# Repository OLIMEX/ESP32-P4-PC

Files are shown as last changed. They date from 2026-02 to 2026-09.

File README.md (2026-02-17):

# ESP32-P4-PC
ESP32-P4 all in one computer with x4 USB hosts Audio, HDMI, MIPI CSI, MIPI DSI, LiPo battery operation, Ethernet with POE

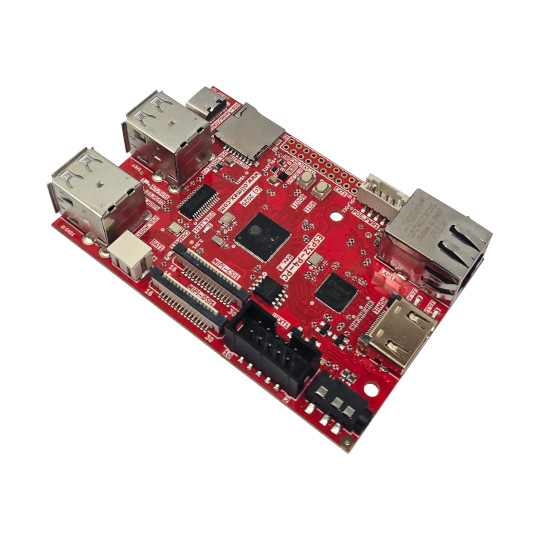
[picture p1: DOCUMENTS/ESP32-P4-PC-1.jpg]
ESP32-P4-PC-1


https://www.olimex.com/Products/IoT/ESP32-P4/ESP32-P4-PC/open-source-hardware

## Licensee
* Hardware is released under CERN Open Hardware Licence Version 2 - Strongly Reciprocal
* Software is released under MIT Licensee
* Documentation is released under CC BY-SA 4.0

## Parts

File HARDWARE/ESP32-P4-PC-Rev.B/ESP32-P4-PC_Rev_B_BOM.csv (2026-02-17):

Id | Designator | Footprint | Quantity | Designation | Supplier and ref
1 | C73,C72 | C_0402_5MIL_DWS | 2 | NA(27pF/50V/5%/C0G/C0402)
2 | FET7,FET8,FET4,FET3,FET6,FET5 | SOT23 | 6 | BSS138(SOT-23)
3 | +5V1,DC_VIN1,GND1,+5V_POE1,VBAT1,+5V_EXT1,+5V_USB1,3.3V1,VO4,GND2,CORE1,VO2,VO3,VO1 | TESTPAD_40-ROUND | 14 | TESTPAD
4 | R86,R64,R85,R48,R83,R70,R42,R43,R67,R27,R55,R66,R102,R68,R54,R41,R3 | R_0402_5MIL_DWS | 17 | 10k/R0402
5 | USB-Serial/JTAG1 | USB2.0_TYPE-C(A40-00119-A52-12)_Paste | 1 | USB-C-16P-F(A40-00119-A52-12)
6 | MIPI-CSI1,MIPI-DSI1 | TE_1-1734248-5 | 2 | FPA-VZA2-15-LF
7 | HDMI1 | HDMI-SWM-19_Paste | 1 | HDMI-SWM-19
8 | USER_LED1,LED_LINK1,LED_HOST3,LED_HOST4,LED_HOST2,LED_HOST1 | LED_0603_KA | 6 | LED/GREEN/0603
9 | C28,C27 | C_0402_5MIL_DWS | 2 | 150pF/50V/2%/NP0/C0402
10 | C38,C107,C106,C105,C95,C30,C21,C19,C7,C52,C91,C109,C112,C108,C111,C69,C4,C121,C96,C40,C53,C87,C51,C85,C46,C5,C23,C119,C42,C131,C57,C11,C49,C43,C12,C47,C32,C9,C101,C128,C94,C115,C120,C54,C31,C71 | C_0402_5MIL_DWS | 46 | 100nF/10V/20%/X5R/C0402
11 | C114,C113,C25,C80,C81,C79,C24 | C_0402_5MIL_DWS | 7 | 27pF/50V/5%/C0G/C0402
12 | BOOT1,RST1 | YTS-A016-X | 2 | YTS-A016-X
13 | R21,R12,R69,R11,R7,R10,R33,R49,R22,R37 | R_0402_5MIL_DWS | 10 | 4.7k/R0402
14 | R74,R84,R73,R88,R8,R72,R9,R91,R4,R39,R61,R82,R93,R92,R62,R56,R57,R80 | R_0402_5MIL_DWS | 18 | 2.2k/R0402
15 | R94,R90,R96 | R_0402_5MIL_DWS | 3 | 470k/R0402
16 | R26,R15,R16,R14,R25,R38 | R_0402_5MIL_DWS | 6 | 22R/R0402
17 | L4,L3 | L_2016_MM | 2 | 1.0uH/4.2A/DCR=35mR/20%/2.00x1.60x1.00mm/L2016(PIM201610-1R0MTS00)
18 | C14,C65,C74,C129,C133,C134,C136,C118,C132,C93,C130,C92 | C_0805_5MIL_DWS | 12 | 47uF/6.3V/20%/X5R/C0805
19 | C35,C102,C103,C123,C63,C75,C37,C124,C66 | C_0603_5MIL_DWS | 9 | 22uF/6.3V/20%/X5R/C0603
20 | Q6,Q2 | TSX-3.2x2.5mm_GND(3) | 2 | Q25MHz/18pF/30ppm/4P/3.2x2.5mm(ABM8-25.000MHZ-D2Y-T)
21 | Q3 | TSX-3.2x2.5mm_GND(3) | 1 | Q40.000MHz/12pF/10ppm/4P/3.2x2.5x0.70mm(Harmony_Electronics_CORP./HSX321S)
22 | R87 | R_0402_5MIL_DWS | 1 | 1M/R0402
23 | C1,C45,C2,C44 | C_0402_5MIL_DWS | 4 | 22pF/50V/5%/C0G/C0402
24 | LED_ACT1,CHARGE1 | LED_0603_KA | 2 | LED/Yellow/0603
25 | UEXT1 | GBH-254-SMT-10 | 1 | P-B-V-10-LF
26 | Q1 | CM7V-T1A(Crystal_Package-1206_3.20x1.50x0.65mm) | 1 | Q32.768kHz/12.5pF/2P/SMD1206
27 | U1 | QFN104_10mm×10mm_Pitch_0.35mm | 1 | ESP32-P4NRWxx(QFN104)
28 | R46,R47 | R_0402_5MIL_DWS | 2 | 10.5k/1%/R0402
29 | U9,U10,U11 | SLP2510P8_TEST | 3 | NA(RCLAMP0524P(SLP2510P8))
30 | C29,C6,C18,C67,C82,C99,C3,C56,C22,C68,C20,C50,C70,C76,C41 | C_0402_5MIL_DWS | 15 | 10uF/6.3V/20%/X5R/C0402
31 | C16,C15 | C_0603_5MIL_DWS | 2 | 100nF/50V/20%/Y5V/C0603
32 | U7 | SSOP28_10x4mm_Pitch_0.64mm | 1 | FE1.1s(SSOP-28)
33 | R63,R32,R19,R81 | R_0402_5MIL_DWS | 4 | NA/R0402
34 | USB_HOST3-4,USB_HOST1-2 | USB_TWO_LEVEL | 2 | USBB1-FRWH-4A(USB-Ax2)
35 | BAT1 | PH2.0-2AT(BAT) | 1 | PH2.0-2AT
36 | R76 | R_0402_5MIL_DWS | 1 | 6.04k/1%/R0402
37 | FID2,FID4,FID6,FID8 | Fiducial1x3_Paste | 4 | Fiducial
38 | U3 | SO-8_208mil | 1 | W25Q128JVSIQ(16MB)
39 | PWR1,ACT/SUS1 | LED_0603_KA | 2 | LED/RED/0603
40 | U5,U4 | SOT-563-6 | 2 | TPS62A02ADRLR(SOT-563-6)
41 | U12 | QFN64_7.5x7.5mm_Pitch_0.4mm | 1 | LT8912B(QFN64)
42 | R36 | R_0402_5MIL_DWS | 1 | 220k/R0402
43 | LAN1 | RJP-003TC1(LPJ4112CNL) | 1 | RJP-003TC1(LPJ4112CNL)
44 | R65,R75,R71 | R_0402_5MIL_DWS | 3 | 100k/R0402
45 | Q4 | TSX-3.2x2.5mm_GND(3) | 1 | Q12MHz/18pF/30ppm/4P/3.2x2.5mm(ABM8-12.000MHZ-D2Y-T)
46 | MICRO_SD1 | TFC-WPAPR-08 | 1 | TFC-WPAPR-08-LF
47 | L1,L7,L8,L2,L5,L6 | L_0805_5MIL_DWS | 6 | 600OHM/2A/UPZ2012E-601-2R0TF/0805
48 | HEADSETS1 | PJ-320D | 1 | PJ-320D
49 | C117 | CPOL-RM3.5mm_8.0x11.5mm_PTH | 1 | 1000uF/10V/20%
50 | POE_PWR1 | PH2.0-4PLB | 1 | PH2.0-4AT
51 | C62,C59 | C_0402_5MIL_DWS | 2 | NA(120pF/50V/5%/C0G/C0402)
52 | EXT1 | HN2x10 | 1 | NA(HN2x10)
53 | C60,C33 | C_0402_5MIL_DWS | 2 | NA(100nF/10V/20%/X5R/C0402)
54 | MH1,MH2,MH3 | Mounting_Hole_Drill-3.3mm_Clerance-7mm | 3 | Mounting_Hole_NPTH
55 | FID3,FID1,FID7,FID5 | Fiducial1x3 | 4 | Fiducial
56 | R13 | R_0402_5MIL_DWS | 1 | 10M/R0402
57 | DCDC_Vin1 | SJ_2_SMALL_12_TIED | 1 | Closed(1-2)
58 | C110 | C_0402_5MIL_DWS | 1 | 2.2nF/50V/10%/X7R/C0402
59 | PWR_SENS_E1,BAT_SENS_E1,BAT_SENS_E2 | SJ_1_SMALLER | 3 | Opened
60 | C61,C36,C88,C48,C97,C84,C55,C58,C98,C39,C86,C100,C10,C126,C104,C8 | C_0402_5MIL_DWS | 16 | 1uF/6.3V/10%/X5R/C0402
61 | R5,R6 | R_0402_5MIL_DWS | 2 | 5.1k/1%/R0402
62 | R103,R89 | R_0402_5MIL_DWS | 2 | 6.81k/1%/R0402
63 | C125,C135,C90,C89,C127,C116 | C_0805_5MIL_DWS | 6 | NA(47uF/6.3V/20%/X5R/C0805)
64 | R2,R1 | R_0402_5MIL_DWS | 2 | 4.02k/1%/R0402
65 | U15 | SOT-23-5 | 1 | TP4054-42-SOT25-R(SOT23-5)
66 | C122,C34,C64 | C_0603_5MIL_DWS | 3 | NA(22uF/6.3V/20%/X5R/C0603)
67 | R50 | R_0402_5MIL_DWS | 1 | 110R/1%/R0402
68 | R35,R34 | R_0402_5MIL_DWS | 2 | 1.5k/R0402
69 | R78 | R_0402_5MIL_DWS | 1 | NA(200R/R0402)
70 | L9 | L_0805_5MIL_DWS | 1 | NA(600OHM/2A/UPZ2012E-601-2R0TF/0805)
71 | R29,R30 | R_0402_5MIL_DWS | 2 | NA(2.2k/R0402)
72 | L11 | CD42(43) | 1 | 4.7uH/2.33A/DCR=70mR/20%/CD43(NRS4018T4R7MDGJ)
73 | D4 | SMA-KA | 1 | 1N5822/SS34/SMA
74 | R17 | R_0402_5MIL_DWS | 1 | 6.19k/1%/R0402
75 | R77 | R_0402_5MIL_DWS | 1 | 10R/R0402
76 | R52 | R_0402_5MIL_DWS | 1 | 240R/1%/R0402
77 | R53 | R_0402_5MIL_DWS | 1 | 2.7k/1%/R0402
78 | C26,C83 | C_0402_5MIL_DWS | 2 | NA(10uF/6.3V/20%/X5R/C0402)
79 | D2,D3 | SOD-123_1C-2A_KA | 2 | 1N5819S4(SOD123)
80 | Q5 | SOT23 | 1 | BC817-40
81 | VR2 | SOT-23-5 | 1 | AP1231-3.3V(SOT23-5)
82 | R24,R105 | R_0402_5MIL_DWS | 2 | 24.9k/1%/R0402
83 | R28,R18 | R_0402_5MIL_DWS | 2 | NA(10k/R0402)
84 | R95 | R_0402_5MIL_DWS | 1 | 8.25k/1%/R0402
85 | VR1 | SOT223 | 1 | LD1117AG-AD-AA3-A-R
86 | C77,C78 | C_0402_5MIL_DWS | 2 | 20pF/50V/5%/NP0/C0402
87 | R45 | R_0402_5MIL_DWS | 1 | 6.49k/1%/R0402
88 | R51 | R_0402_5MIL_DWS | 1 | 49.9k/1%/R0402
89 | R59,R58,R60 | R_0402_5MIL_DWS | 3 | 33R/R0402
90 | U6 | SOT23-6 | 1 | CH217K(SOT23-6L)
91 | U14 | SOT23-6 | 1 | MT3608(SOT23-6)
92 | R23 | R_0402_5MIL_DWS | 1 | NA(4.7k/R0402)
93 | R31 | R_0603_5MIL_DWS | 1 | 0R/R0603
94 | U2 | QFN32_EP(33)_4.00x4.00x0.80mm_Pitch_0.40mm | 1 | IP101GRR(32-PIN_QFN)
95 | C17 | C_1206_5MIL_DWS_ISO | 1 | 1nF/2000V/10%/X7R/C1206
96 | R98 | R_0402_5MIL_DWS | 1 | 1.05k/1%/R0402
97 | R40 | R_0402_5MIL_DWS | 1 | NA(0R/R0402)
98 | R79 | R_0402_5MIL_DWS | 1 | 200R/R0402
99 | U16,U13 | SOT-5X3 | 2 | TPS2116
100 | RM2 | RA0805_(4X0402)_xx_BIGGEROUTPADS | 1 | RA0805_(4X0402)_33R
101 | U8 | QFN-20_EP(21)_3x3x0.6mm_Pitch_0.4mm | 1 | ES8311(QFN-20)
102 | RM1 | RA0805_(4X0402)_xx_BIGGEROUTPADS | 1 | RMAT_(4x0402)_4.7k
103 | TVS1 | SOT-23-5 | 1 | ESDS314DBVR(SOT-23-5)
104 | C13 | C_0402_5MIL_DWS | 1 | 4.7uF/X5R/20%/10V/C0402
105 | FET1 | SOT23 | 1 | IRLML6402(SOT-23)
106 | R44 | R_0402_5MIL_DWS | 1 | 30.1k/1%/R0402
107 | R20 | R_0402_5MIL_DWS | 1 | NA(10M/R0402)

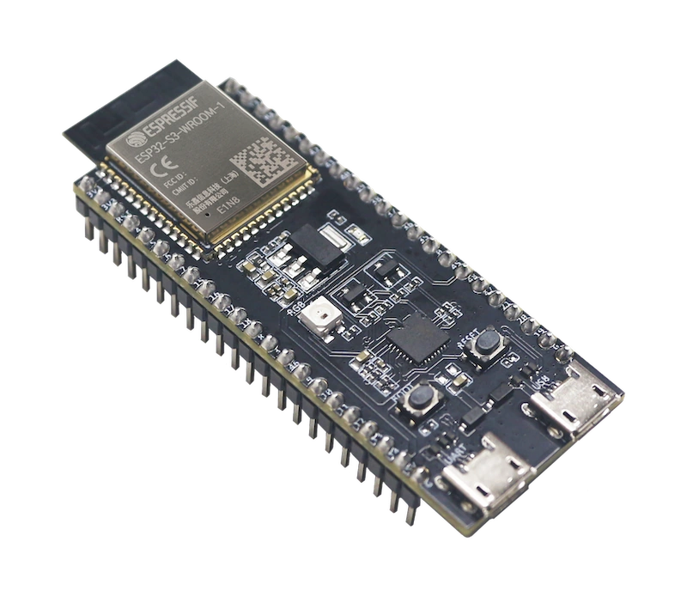
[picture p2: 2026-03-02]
SOFTWARE/ESP-IDF/p4_production_test/components/esp-bsp/bsp/esp_bsp_devkit/doc/esp_bsp_devkit.webp

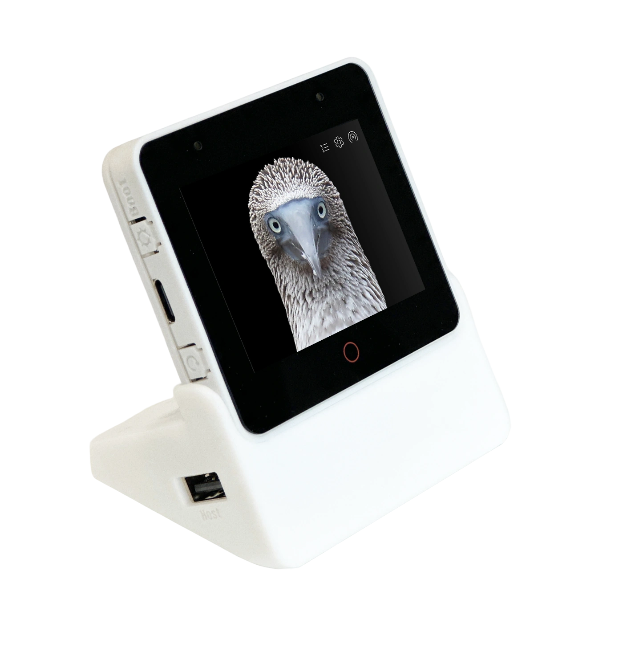
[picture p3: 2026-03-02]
SOFTWARE/ESP-IDF/p4_production_test/components/esp-bsp/bsp/esp-box-3/doc/esp-box-3.webp

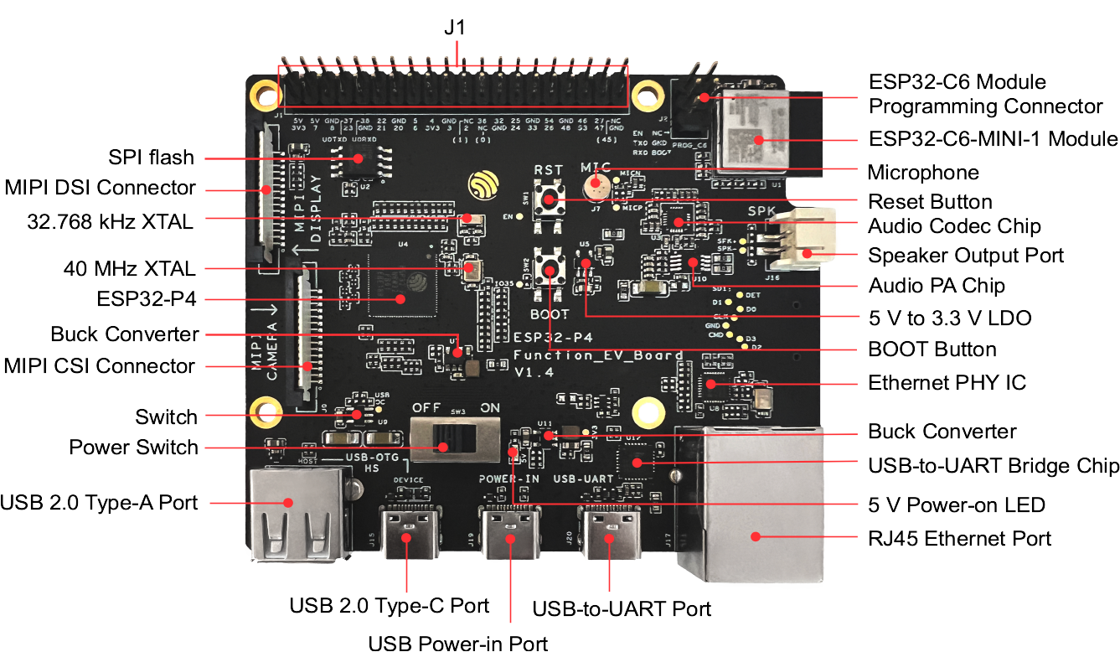
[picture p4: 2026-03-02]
SOFTWARE/ESP-IDF/p4_production_test/components/esp-bsp/bsp/esp32_p4_function_ev_board/doc/esp32-p4-function-ev-board-annotated-photo-front.png

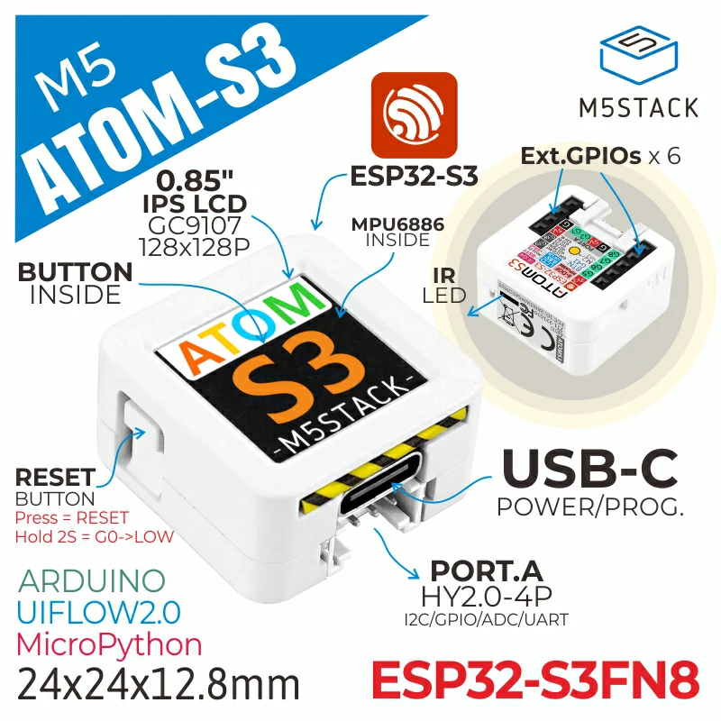
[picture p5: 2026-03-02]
SOFTWARE/ESP-IDF/p4_production_test/components/esp-bsp/bsp/m5_atom_s3/doc/pic.webp

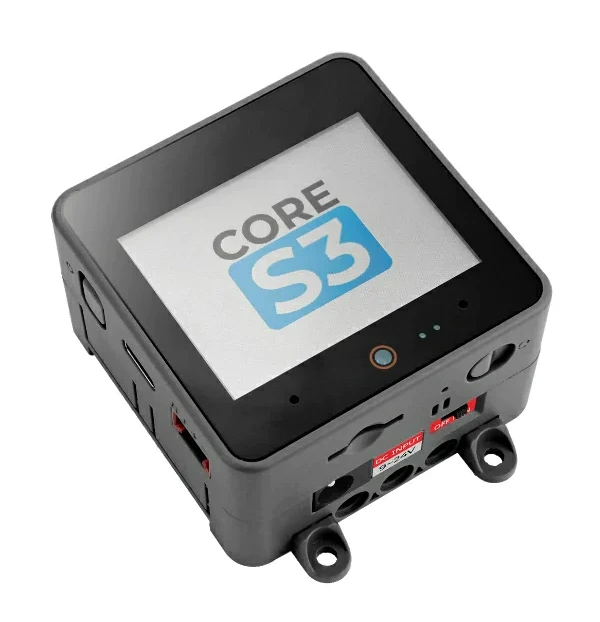
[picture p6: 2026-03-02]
SOFTWARE/ESP-IDF/p4_production_test/components/esp-bsp/bsp/m5stack_core_s3/doc/m5stack_core_s3.webp

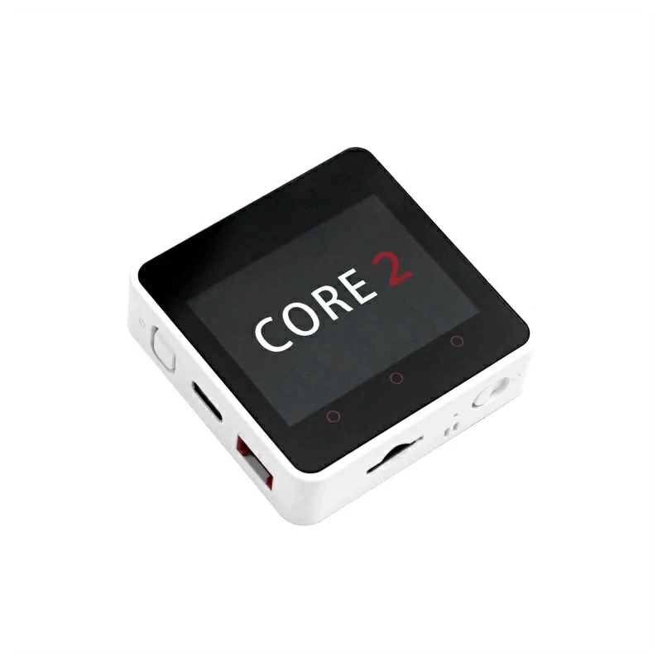
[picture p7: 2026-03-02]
SOFTWARE/ESP-IDF/p4_production_test/components/esp-bsp/bsp/m5stack_core_2/doc/m5stack_core_2.webp

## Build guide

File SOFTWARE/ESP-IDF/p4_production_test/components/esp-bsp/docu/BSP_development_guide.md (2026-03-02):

# Board Support Package development guide

This guide describes necessary steps to add a new BSP to the esp-bsp project.

### New BSP requirements
* We want the BSPs to be used by as many users and projects as possible. All BSP must support IDF from version 4.4 up to latest release. Boards that were released after IDF v5.0 do not have to be backward compatible with v4.4.
* We want the BSPs to provide a 'board abstraction layer' that allows the user to run his application on a range of different boards. Public API for each BSP must be the same. The API consistency is ensured by conventions described below.
* We want the main features to be clearly visible for new users. Each new BSP must be added to a table of supported boards in root [README.md](https://github.com/espressif/esp-bsp/blob/master/README.md) it must contain a license (Apache-2) and a README.md file. Conventions for the readme file are described below
* All BSPs are uploaded to [ESP Registry](https://components.espressif.com/). So each BSP must contain `idf_component.yml` file and must be added to [CI upload job](https://github.com/espressif/esp-bsp/blob/master/.github/workflows/upload_component.yml). The `idf_component.yml` must contain: version, description, url, target and (optional) dependencies.
* We want to provide LVGL users with easy, out-of-the-box working solution for their GUI applications. Each board that has a display must be added to LVGL's [SquareLineStudio](https://squareline.io/) pre-defined boards. For more information refer to [this readme](https://github.com/espressif/esp-bsp/blob/master/SquareLine/README.md).
    * List of currently implemented LCD drivers is maintained in a [separate table](https://github.com/espressif/esp-bsp/blob/master/docu/LCD.md)
* We have an experimental idf.py extension, [bsp_ext.py](https://github.com/espressif/esp-bsp/blob/master/examples/bsp_ext.py) that allows changing of BSP during project configuration. Please add new BSPs to the list in this file.

### API conventions

BSP is a standard IDF component. You can start development by `idf.py create-component your_bsp_name`.

The APIs that a BSP can offer depend on the boards capabilities. For example, a board that contains audio codec will expose audio API and a board with display and touch controller will expose display and touch API.

#### General
* The boards capabilities must be listed in its header file, similarly to `SOC_CAPS_*` macro used in esp-idf. For example:
``` c
/**************************************************************************************************
 *  BSP Capabilities
 **************************************************************************************************/

#define BSP_CAPS_DISPLAY        1
#define BSP_CAPS_TOUCH          1
#define BSP_CAPS_BUTTONS        1
#define BSP_CAPS_AUDIO          1
#define BSP_CAPS_AUDIO_SPEAKER  1
#define BSP_CAPS_AUDIO_MIC      1
#define BSP_CAPS_SDCARD         0
#define BSP_CAPS_IMU            1
```
* Each BSP must provide a wrapper header file that can be included by `#include "bsp/esp-bsp.h"`
* BSPs that expose display and touch APIs must provide a header file `bsp/display.h` and `bsp/touch.h` that contain functions for display/touch initialization without graphical library (LVGL)
* Complete board's pinout must be in the beginning of the BSP's header file

#### I2C
* I2C can be used by many devices on the bus. The 'init' call must support multiple invocations
* Uses Kconfig for I2C peripheral selection
* Functions, which must be defined in BSP *.c file:
``` c
esp_err_t bsp_i2c_init(void);
esp_err_t bsp_i2c_deinit(void);
```
* See any BSP

#### Display
* BSPs with display are shipped with [LVGL](https://components.espressif.com/components/lvgl/lvgl) component by default. For version without LVGL, you can use BSP version with `noglib` suffix (eg. `esp32_s3_eye_noglib`)
* Display functions are divided into two parts. The first part is HW initialization only (include/bsp/display.h), second part is initialization of the display and LVGL (bsp/esp-bsp.h)
* HW initialization functions, which must be defined in bsp/display.h file:
``` c
esp_err_t bsp_display_new(const bsp_display_config_t *config, esp_lcd_panel_handle_t *ret_panel, esp_lcd_panel_io_handle_t *ret_io);
esp_err_t bsp_display_brightness_set(int brightness_percent);
esp_err_t bsp_display_backlight_on(void);
esp_err_t bsp_display_backlight_off(void);
```
* LVGL init function, which must be defined in bsp/esp-bsp.h file:
``` c
lv_disp_t *bsp_display_start(void);
lv_disp_t *bsp_display_start_with_config(const bsp_display_cfg_t *cfg);
bool bsp_display_lock(uint32_t timeout_ms);
void bsp_display_unlock(void);
void bsp_display_rotate(lv_disp_t *disp, lv_disp_rot_t rotation);
```
* See esp_wrover_kit, esp32_s2_kaluga_kit ...

#### LCD Touch
* LCD touch drivers are build around base [esp_lcd_touch](https://components.espressif.com/components/espressif/esp_lcd_touch) component
* BSPs with touch display are shipped with [LVGL](https://components.espressif.com/components/lvgl/lvgl) component by default. For version without LVGL, you can use BSP version with `noglib` suffix (eg. `esp32_s3_eye_noglib`)
* If LVGL is used, the touch controller is initialized together with display. If LVGL is not used you can use HW initialization functions from bsp/touch.h
* HW initialization function, which must be defined in bsp/touch.h file:
``` c
esp_err_t bsp_touch_new(const bsp_touch_config_t *config, esp_lcd_touch_handle_t *ret_touch);
```
* LVGL get input device function for advanced scenarios in bsp/esp-bsp.h
``` c
lv_indev_t *bsp_display_get_input_dev(void);
```
* See esp-box, esp-box-3 ...

#### SPI Flash File System
* The SPIFFS is supported by all ESP chips internally. It allows the users to store large files (pictures, recordings...)
* Functions, which must be defined in BSP *.c file:
``` c
esp_err_t bsp_spiffs_mount(void);
esp_err_t bsp_spiffs_unmount(void);
```
* Uses Kconfig for SPIFFS settings
* See any BSP

#### SD card
* Functions, which should be defined in BSP *.c file:
``` c
esp_err_t bsp_sdcard_mount(void);
esp_err_t bsp_sdcard_unmount(void);
```
* Uses Kconfig for mountpoint and possible `format_on_fail` settings
* See esp_wrover_kit

> @todo We still use `extern sdmmc_card_t *bsp_sdcard;` which is very ugly :( Tracked in BSP-189

> @todo We could reuse code from https://github.com/espressif/esp-box/blob/master/components/bsp/src/storage/bsp_sdcard.c

#### Buttons
* We want to provide unified API for all types of buttons
* Buttons feature is covered by [button](https://components.espressif.com/components/espressif/button) component. It allows usage of GPIO, ADC, io_expander and even capacitive buttons with various events (pressed, released, double click, long press...)
* All buttons must be added to enum `bsp_button_t`
* All buttons must be initialized in the following call
``` c
esp_err_t bsp_iot_button_create(button_handle_t btn_array[], int *btn_cnt, int btn_array_size);
```
* See esp32_s2_kaluga_kit

#### LEDs
* Similarly to buttons, we want to provide unified API for all types of LEDs (classic, RGB, addressable RGB)
* LEDs feature is covered by [led_indicator](https://components.espressif.com/components/espressif/led_indicator) component. It support all aforementioned types of LEDs with various control options (brightness, color, transitions...)
* All LEDs must be initialized in the following call
``` c
esp_err_t bsp_led_indicator_create(led_indicator_handle_t led_array[], int *led_cnt, int led_array_size);
```
* See esp32_s3_korvo_1

#### Audio
* Audio feature is covered by [esp_codec_dev](https://components.espressif.com/components/espressif/esp_codec_dev) component
* BSP provides API for easy initialization:
``` c
esp_err_t bsp_audio_init(const i2s_std_config_t *i2s_config);
const audio_codec_data_if_t *bsp_audio_get_codec_itf(void);
esp_codec_dev_handle_t bsp_audio_codec_speaker_init(void);
esp_codec_dev_handle_t bsp_audio_codec_microphone_init(void);
```
* See esp32_s3_korvo_2, esp32_s2_kaluga_kit

#### Camera
* Camera feature is covered by [esp32-camera](https://components.espressif.com/components/espressif/esp32-camera) component
* There is no API needed. We only provide pinout and default camera configuration macro `BSP_CAMERA_DEFAULT_CONFIG`
* See esp32_s2_kaluga_kit, esp32_s3_eye

#### USB
* Only provide pinout for completeness
* See esp32_s3_usb_otg

### README.md conventions
> @todo tracked in BSP-362

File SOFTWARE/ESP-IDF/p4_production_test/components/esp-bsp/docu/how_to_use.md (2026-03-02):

# How to Use the ESP-BSP API

<div align="center">

| :pager: [DISPLAY & TOUCH](#pager-display--touch) | :musical_note: [AUDIO](#musical_note-audio) | :floppy_disk: [SD & SPIFFS](#floppy_disk-sd-card--spi-flash-file-storage) | :camera: [CAMERA](#camera-camera) |
| :---: | :---: | :---: | :---: |

| :radio_button: [BUTTONS](#radio_button-buttons) | :bulb: [LEDS](#bulb-leds) | :battery: [BATTERY](#battery-battery) | :electric_plug: [USB](#electric_plug-usb) | :video_game: [IMU & Sensors](#video_game-imu--sensors) |
| :---: | :---: | :---: | :---: | :---: |

</div>

## Overview

This document provides a unified overview of the ESP-BSP (Board Support Package) API. It is shared across all supported BSPs. Each BSP **may not implement all APIs listed here**, but **should provide implementations for all APIs relevant to the capabilities it supports**.

The goal of this document is to make it easier for developers to understand the available APIs and how to use them consistently across different boards.

## General

### Identification

Each BSP defines an identifier macro in the form of `BSP_BOARD_*`.

### Capabilities

Each BSP defines a set of capability macros that indicate which features are supported.
The list may look like this:

```
#define BSP_CAPS_DISPLAY        1
#define BSP_CAPS_TOUCH          1
#define BSP_CAPS_BUTTONS        1
#define BSP_CAPS_AUDIO          1
#define BSP_CAPS_AUDIO_SPEAKER  1
#define BSP_CAPS_AUDIO_MIC      1
#define BSP_CAPS_SDCARD         1
#define BSP_CAPS_IMU            0
```

You can use these macros to conditionally compile code depending on feature availability.

### Pinout

Each BSP defines a set of macros for default pin assignments used by its hardware peripherals.
These macros allow users to configure or reference standard interfaces like I2C, SPI, LCD, audio, or SD cards easily.

- I2C: `BSP_I2C_*`
- Display: `BSP_LCD_*`
- Audio I2S: `BSP_I2S_*`
- USB: `BSP_USB_*`
- SD Card (MMC): `BSP_SD_*`
- SD Card (SPI): `BSP_SD_SPI_*`

> [!NOTE]
> Not all boards support all interfaces. You should always check if the related capability macro (e.g., BSP_CAPS_SDCARD) is defined.

### I2C

Some devices included in BSPs (e.g., sensors, displays, audio codecs) communicate via the I2C interface. In many cases, I2C is initialized automatically as part of the device setup. However, you can manually initialize or deinitialize the I2C peripheral using the following API:

```
/* Initialize the default I2C bus used by the BSP */
bsp_i2c_init();

...

/* Deinitialize the I2C bus */
bsp_i2c_deinit();
```

If you need direct access to the initialized I2C bus (e.g., to communicate with an external peripheral not handled by the BSP), you can retrieve the I2C bus handle:

```
i2c_master_bus_handle_t i2c = bsp_i2c_get_handle();
```

> [!NOTE]
> The BSP ensures that I2C initialization is performed only once, even if called multiple times. This helps avoid conflicts when multiple components rely on the same I2C bus.

### ADC

Some devices included in BSPs (such as buttons, battery monitoring, etc.) use the ADC peripheral. In most cases, the ADC is automatically initialized as part of the specific device setup. However, you can manually initialize the ADC using the following API:

```
/* Initialize the ADC peripheral */
bsp_adc_initialize();
```

If you need direct access to the ADC instance (e.g., for custom measurements), you can retrieve the handle:

```
adc_oneshot_unit_handle_t adc = bsp_adc_get_handle();
```

> [!NOTE]
> The BSP ensures the ADC is initialized only once, even if `bsp_adc_initialize()` is called multiple times.

### Features

Some boards support enabling or disabling specific hardware features (such as LCD, SD card, camera, etc.) to reduce power consumption or manage shared resources. The BSP provides a unified API to control these features:

```
/* Enable the LCD feature */
bsp_feature_enable(BSP_FEATURE_LCD, true);

/* Disable the speaker to reduce power usage */
bsp_feature_enable(BSP_FEATURE_SPEAKER, false);
```

Supported feature flags (may vary depending on the board):
- `BSP_FEATURE_LCD` - Display module
- `BSP_FEATURE_TOUCH` - Touch controller
- `BSP_FEATURE_SD` - SD card interface
- `BSP_FEATURE_SPEAKER`-  Audio speaker
- `BSP_FEATURE_BATTERY` - Battery monitoring
- `BSP_FEATURE_VIBRATION` - Vibration motor

> [!NOTE]
> Not all BSPs support feature toggling, and some features may not be available or controllable via this API. Always check the BSP header or documentation for supported features.

> [!TIP]
> Disabling unused features can help reduce power consumption, especially in battery-powered applications.

## :pager: Display & Touch

### Initialization

ESP-BSP provides two ways to initialize the **display**, **touch** and **LVGL**.

Simple method:

```
/* Initialize display, touch, and LVGL */
lv_display_t display = bsp_display_start();
```

Configurable method:

```
bsp_display_cfg_t cfg = {
    .lvgl_port_cfg = ESP_LVGL_PORT_INIT_CONFIG(),   /* See LVGL Port for more info */
    .buffer_size = BSP_LCD_V_RES * BSP_LCD_H_RES,   /* Screen buffer size in pixels */
    .double_buffer = true,                          /* Allocate two buffers if true */
    .flags = {
        .buff_dma = true,                           /* Use DMA-capable LVGL buffer */
        .buff_spiram = false,                       /* Allocate buffer in PSRAM if true */
    }
};
cfg.lvgl_port_cfg.task_stack = 10000;   /* Example: change LVGL task stack size */
/* Initialize display, touch, and LVGL */
lv_display_t display = bsp_display_start_with_config(&cfg);
```

After initialization, you can use the [LVGL](https://docs.lvgl.io/master/) API or [LVGL Port](../components/esp_lvgl_port/README.md) API.

### Initialization without LVGL - NoGLIB BSP

To initialize the LCD without LVGL, use:

```
esp_lcd_panel_handle_t panel_handle;
esp_lcd_panel_io_handle_t io_handle;
const bsp_display_config_t bsp_disp_cfg = {
    .max_transfer_sz = (BSP_LCD_H_RES * 100) * sizeof(uint16_t),
};
BSP_ERROR_CHECK_RETURN_NULL(bsp_display_new(&bsp_disp_cfg, &panel_handle, &io_handle));
```

To initialize the LCD touch without LVGL, use:

```
esp_lcd_touch_handle_t tp;
bsp_touch_new(NULL, &tp);
```

After initialization, you can use the [ESP-LCD](https://docs.espressif.com/projects/esp-idf/en/latest/esp32/api-reference/peripherals/lcd/index.html) API and [ESP-LCD Touch](../components/lcd_touch/README.md) API.

### Set Brightness

```
/* Set display brightness to 100% */
bsp_display_backlight_on();

/* Set display brightness to 0% */
bsp_display_backlight_off();

/* Set display brightness to 50% */
bsp_display_brightness_set(50);
```

> [!NOTE]
> Some boards do not support changing brightness. They return an `ESP_ERR_NOT_SUPPORTED` error.

### LVGL API Usage (only when initialized with LVGL)

All LVGL calls must be protected using lock/unlock:

```
/* Wait until other tasks finish screen operations */
bsp_display_lock(0);
...
lv_obj_t * screen = lv_disp_get_scr_act(disp_handle);
lv_obj_t * obj = lv_label_create(screen);
...
/* Unlock after screen operations are done */
bsp_display_unlock();
```

### Screen rotation (only when initialized with LVGL)

```
bsp_display_lock(0);
/* Rotate display to 90° */
bsp_display_rotate(display, LV_DISPLAY_ROTATION_90);
bsp_display_unlock();
```

> [!NOTE]
> Some LCDs do not support hardware rotation and instead use software rotation, which consumes more memory.

### Available constants

Constants like screen resolution, pin configuration, and other options are defined in the BSP header files (`{bsp_name}.h`, `display.h`, `touch.h`).
Below are some of the most relevant predefined constants:

- `BSP_LCD_H_RES` - Horizontal resolution in pixels
- `BSP_LCD_V_RES` - Vertical resolution in pixels
- `BSP_LCD_SPI_NUM` - SPI bus used by the LCD (if applicable)

## :musical_note: Audio

### Initialization

Before using speaker or microphone features, the audio codec must be initialized.

```
/* Initialize the speaker codec */
esp_codec_dev_handle_t spk_codec_dev = bsp_audio_codec_speaker_init();

/* Initialize the microphone codec */
esp_codec_dev_handle_t mic_codec_dev = bsp_audio_codec_microphone_init();
```

After initialization, the [esp_codec_dev](https://components.espressif.com/components/espressif/esp_codec_dev) API can be used to control playback and recording.

> [!NOTE]
> Some BSPs may only support playback (speaker) or only input (microphone). Use the capability macros (`BSP_CAPS_AUDIO`, `BSP_CAPS_AUDIO_SPEAKER`, `BSP_CAPS_AUDIO_MIC`) to check supported features.

### Example of audio usage

#### Speaker

Below is an example of audio playback using the speaker (source data not included):

```
/* Set volume to 50% */
esp_codec_dev_set_out_vol(spk_codec_dev, 50);

/* Define audio format */
esp_codec_dev_sample_info_t fs = {
    .sample_rate = wav_header.sample_rate,
    .channel = wav_header.num_channels,
    .bits_per_sample = wav_header.bits_per_sample,
};
/* Open speaker stream */
esp_codec_dev_open(spk_codec_dev, &fs);

...
/* Play audio data */
esp_codec_dev_write(spk_codec_dev, wav_bytes, wav_bytes_len);
...

/* Close stream when done */
esp_codec_dev_close(spk_codec_dev);
```

> [!TIP]
> Audio data must be in raw PCM format. Use a decoder if playing compressed formats (e.g., WAV, MP3).

#### Microphone

Below is an example of recording audio using the microphone (destination buffer not included):

```
/* Set input gain (optional) */
esp_codec_dev_set_in_gain(mic_codec_dev, 42.0);

/* Define audio format */
esp_codec_dev_sample_info_t fs = {
    .sample_rate = 16000,
    .channel = 1,
    .bits_per_sample = 16,
};
/* Open microphone stream */
esp_codec_dev_open(mic_codec_dev, &fs);

/* Read recorded data */
esp_codec_dev_read(mic_codec_dev, recording_buffer, BUFFER_SIZE)

...

/* Close stream when done */
esp_codec_dev_close(mic_codec_dev);
```

## :floppy_disk: SD Card & SPI Flash File Storage

### SPIFFS Initialization / Deinitialization

Each BSP provides a simple API for mounting and unmounting the SPI Flash File System (SPIFFS).

```
/* Mount SPIFFS to the virtual file system */
bsp_spiffs_mount();

/* ... perform file operations ... */

/* Unmount SPIFFS from the virtual file system */
bsp_spiffs_unmount();
```

### SD Card Initialization / Deinitialization

The BSP offers a flexible API for working with SD cards. In addition to the default mount and unmount functions, you can also use a configuration structure or access preconfigured `host` and `slot` structures.

Mount with Default Configuration

```
/* Mount microSD card to the virtual file system */
bsp_sdcard_mount();

/* ... perform file operations ... */

/* Unmount microSD card */
bsp_sdcard_unmount();
```

Mount with Custom Configuration

Some BSPs allow selecting between SDMMC and SPI interfaces for the SD card. Use the appropriate API function based on your hardware:
```
bsp_sdcard_cfg_t cfg = {0};
/* Mount SD card using SDMMC interface */
bsp_sdcard_sdmmc_mount(&cfg);
```

or

```
bsp_sdcard_cfg_t cfg = {0};
/* Mount SD card using SPI interface */
bsp_sdcard_sdspi_mount(&cfg)
```

> [!NOTE]
> Not all BSPs support both SDMMC and SPI modes. Check the board documentation to see which interfaces are available.
> If an unsupported interface is used, the API will return `ESP_ERR_NOT_SUPPORTED` error.

### After Mounting

Once the SD card or SPIFFS is mounted, you can use standard file I/O functions (`fopen`, `fread`, `fwrite`, `fclose`, etc.) provided by ESP-IDF's VFS (Virtual File System).

To print basic SD card information (after mounting), you can use:
```
sdmmc_card_t *sdcard = bsp_sdcard_get_handle();
sdmmc_card_print_info(stdout, sdcard);
```

> [!TIP]
> The bsp_sdcard_get_handle() function returns a pointer to the sdmmc_card_t structure, which contains detailed information about the connected SD card.

## :camera: Camera

The BSP provides a helper function bsp_camera_start() for initializing the on-board camera module.
This function sets up the required I2C bus, video subsystem, and camera clock if necessary.

### Example Usage

Camera usage can be quite complex. For a complete example, refer to the [`display_camera_csi`](https://github.com/espressif/esp-bsp/tree/master/examples/display_camera_csi) example in the BSP repository, or to the examples provided in the [`esp_video`](https://github.com/espressif/esp-video-components/tree/master/esp_video) component.

> [!NOTE]
> Please, do not forget select right camera sensor in `menuconfig`

## :radio_button: Buttons

Most boards include one or more user buttons. The BSP provides a simple API to initialize and use them.
Internally, it utilizes the [button](https://components.espressif.com/components/espressif/button/) component for event handling and debouncing.

```
/* Initialize all available buttons */
button_handle_t btns[BSP_BUTTON_NUM] = {NULL};
bsp_iot_button_create(btns, NULL, BSP_BUTTON_NUM);

/* Register a callback for button press */
for (int i = 0; i < BSP_BUTTON_NUM; i++) {
    iot_button_register_cb(btns[i], BUTTON_PRESS_DOWN, NULL, btn_handler, (void *) i);
}

/* Called on button press */
static void btn_handler(void *button_handle, void *usr_data)
{
    int button_index = (int)usr_data;
    ESP_LOGI(TAG, "Button %d pressed", button_index);
}
```

**Notes:**
- `BSP_BUTTON_NUM` defines the number of available buttons on the board

- Instead of relying on a numeric index, you can use the `bsp_button_t` structure defined in the BSP header to reference buttons by name (e.g., BSP_BUTTON_MUTE, BSP_BUTTON_MAIN, BSP_BUTTON_BOOT, etc.)

- The callback can be registered for different button events, such as `BUTTON_PRESS_DOWN`, `BUTTON_PRESS_UP`, or `BUTTON_LONG_PRESS_START`, `BUTTON_DOUBLE_CLICK`, ...

- Button features (e.g. long-press support, active level) are configured automatically by the BSP.

## :bulb: LEDs

LEDs are handled similarly to buttons in BSP. The BSP uses the [led_indicator](https://components.espressif.com/components/espressif/led_indicator) component, which provides simple control over LED states and built-in effects such as blinking, breathing, and more. It also supports addressable RGB LEDs.

```
/* Initialize all LEDs */
bsp_led_indicator_create(leds, NULL, BSP_LED_NUM);

/* Set color of the first LED (for addressable RGB LEDs only) */
led_indicator_set_rgb(leds[0], SET_IRGB(0, 0x00, 0x64, 0x64));

/*
Start a predefined LED effect:
- BSP_LED_ON
- BSP_LED_OFF
- BSP_LED_BLINK_FAST
- BSP_LED_BLINK_SLOW
- BSP_LED_BREATHE_FAST
- BSP_LED_BREATHE_SLOW
*/
led_indicator_start(leds[0], BSP_LED_BREATHE_SLOW);
```

**Notes:**
- `BSP_LED_NUM` defines the total number of available LEDs on the board
- LEDs are automatically configured by the BSP (no need to set GPIO or direction manually)

## :battery: Battery

Some boards with battery support can measure the battery voltage using an ADC channel. BSP provides a simple API for this:

```
/* Initialize the battery voltage measurement */
bsp_voltage_init();

/* Read battery voltage in millivolts */
int voltage = bsp_voltage_battery_get();
```

## :electric_plug: USB

Boards with USB support define macros for USB pins, such as `BSP_USB_POS` and `BSP_USB_NEG`, and may also provide control APIs for enabling or disabling USB functionality.

```
/* Initialize USB in device mode and enable power */
bsp_usb_host_start(BSP_USB_HOST_POWER_MODE_USB_DEV, true);

...
/* Deinitialize and stop USB */
bsp_usb_host_stop();
```

> [!NOTE]
> Not all BSPs implement USB support or provide power control. Refer to the board's documentation and the BSP header files for available functions and supported modes.

For more USB-related APIs and configuration options, check the corresponding BSP header files.

## :video_game: IMU & Sensors

Boards with integrated sensors (e.g., IMUs, environmental sensors) are not fully abstracted by the BSP. The BSP does not provide specific APIs for sensor control or data retrieval.

Instead, the BSP includes selected sensor components via the `idf_component.yml` file and assists with peripheral initialization (typically I2C bus configuration).

> [!NOTE]
> Sensor initialization and usage are left to the user. The BSP ensures the I2C bus is properly configured but does not wrap sensor APIs.

For practical usage examples and supported sensors on your board, refer to the relevant examples in the BSP repository, such as:
- `display_rotation` (for IMU setup and orientation control)
- `display_sensors` (for reading sensor data)

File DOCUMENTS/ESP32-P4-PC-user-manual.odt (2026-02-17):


ESP32-P4-PC

User Manual

Rev.1.0 February 2026 olimex.com

# What is ESP32-P4-PC

ESP32-P4-PC (https://www.olimex.com/Products/IoT/ESP32-P4/ESP32-P4-PC/open-source-hardware) is complete all in one computer based on ESP32-P4NRW32 Dual core RISC-V processor from Espressif.

The features of ESP32-P4-PC (https://www.olimex.com/Products/IoT/ESP32-P4/ESP32-P4-PC/open-source-hardware) are:

- Espressif ESP32-P4NRW32 processor: - Dual core 400Mhz RISC-V - 768KB RAM - 32MB PSRAM
- SPI Flash 16MB
- USB JTAG for programming and debugging
- Ethernet MACPHY and connector with POE option via extension (https://www.olimex.com/Products/IoT/ESP32-P4/POEv3/open-source-hardware)
- Camera CSI interface
- LCD Display DSI interface
- HDMI converter and output
- Audio output 3.5mm jack
- LiPo battery charger and step up for Lipo battery operation
- MicroSD card
- Boot and Reset buttons
- UEXT connector
- All free GPIOs available on 0.1″ 2.54 mm 20 pin connector
- Three mounting holes 3.3mm diameter
- Dimensions: (90 x 60)mm
  ESP32-P4-PC (https://www.olimex.com/Products/IoT/ESP32-P4/ESP32-P4-PC/open-source-hardware) is Open Source Hardware, all CAD files and firmware and available, so people can study and modify.

+ Important notice: If ESP32-P4-PC (https://www.olimex.com/Products/IoT/ESP32-P4/ESP32-P4-PC/open-source-hardware) is not mounted in box be careful to not place it on metal surface, nor drop metal objects on top of the PCB! This will lead to damage.

## Order codes for ESP32-P4-PC and accessories:

ESP32-P4-PC (https://www.olimex.com/Products/IoT/ESP32-P4/ESP32-P4-PC/open-source-hardware) ESP32-P4 all in one computer with 4 USB hosts and HDMI display

CAMERA-OV5647-5MPIX (https://www.olimex.com/Products/Components/Camera/CAMERA-OV5647-5MPIX/) MIPI CSI compatible camera

MIPI-LCD2.8-640x480 (https://www.olimex.com/Products/RaspberryPi/MIPI-LCD2.8-640x480/) MIPI DSI compatible display

POEv3 (https://www.olimex.com/Products/IoT/ESP32-P4/POEv3/open-source-hardware) POE module compatible with ESP32-P4-PC

CABLE-IDC10-15CM (https://www.olimex.com/Products/Modules/Adapters/CABLE-IDC10-15cm/) UEXT cable

USB-KEYBOARD-PS2 (https://www.olimex.com/Products/USB-Modules/USB-KEYBOARD-PS2/) USB keyboard which is compatible with ESP32-P4-PC

USB-CABLE-AM-USB3-C (https://www.olimex.com/Products/Components/Cables/USB-CABLE-AM-USB3-C/) High speed, High current cable for power supply and programming

CABLE-HDMI-50CM (https://www.olimex.com/Products/Components/Cables/CABLE-HDMI-50CM/) HDMI cable

UEXT modules (https://www.olimex.com/Products/Modules/) many UEXT modules which can connect to Neo6502 UEXT connector

BATTERY-LiPo (https://www.olimex.com/Products/Power-Supply/Lipo-battery/BATTERY-LIPO1400mAh/)1400mAh (https://www.olimex.com/Products/Power-Supply/Lipo-battery/BATTERY-LIPO1400mAh/) LiPo battery compatible with RP2350pc

(https://www.olimex.com/Products/Components/Cables/USB-CABLE-AM-USB3-C/)

# HARDWARE

## ESP32-P4-PC layout:

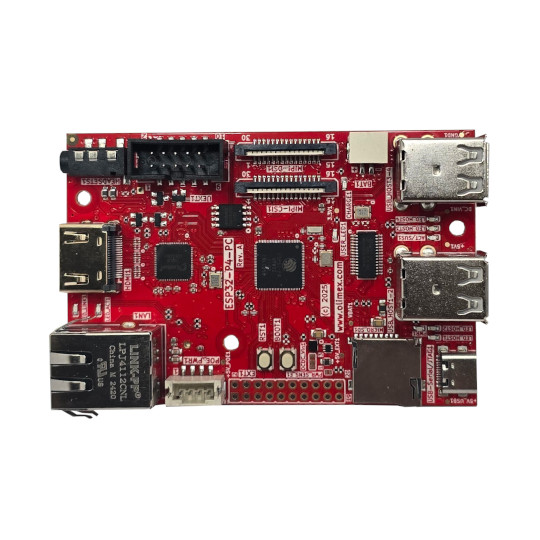
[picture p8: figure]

Camera MIPI

LiPo battery

Audio 3.5mm jack

UEXT

Display MIPI

USB 3-4

USB 1-2

USB-C

Micro SD card

GPIO extension

Boot button

Reset button

POE connector

Ethernet 10/100Mb

HDMI

## UEXT connector:

UEXT connector stands for Universal EXTension connector and contain +3.3V, GND, I2C, SPI, UART signals.

UEXT connector can be in different shapes.

The original UEXT connector is 0.1” 2.54mm step boxed plastic connector. All signals are with 3.3V levels.

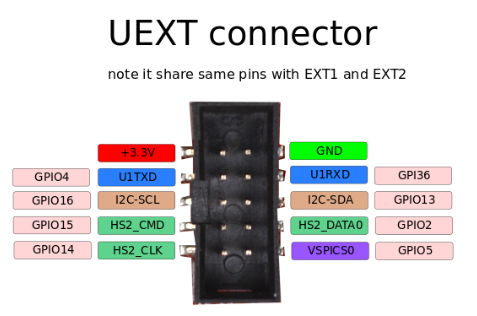
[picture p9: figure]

Olimex has developed number of MODULES (https://www.olimex.com/Products/Modules/) with this connector. There are temperature, humidity, pressure, magnetic field, light sensors. Modules with LCDs, LED matrix, Relays, Bluetooth, Zigbee, WiFi, GSM, GPS, RFID, RTC, EKG, sensors and etc.

## ESP32-P4-PC UEXT connectors:

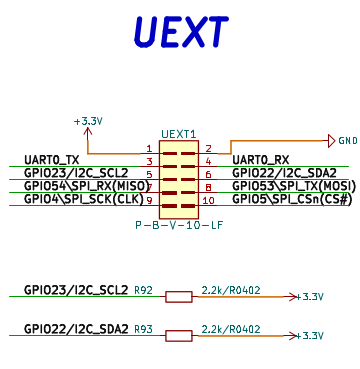
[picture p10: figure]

## SD-card interface:

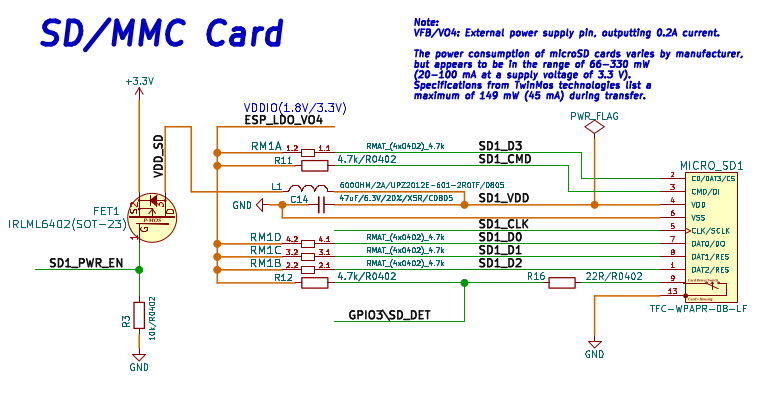
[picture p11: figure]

## MIPI CSI and DSI connectors:

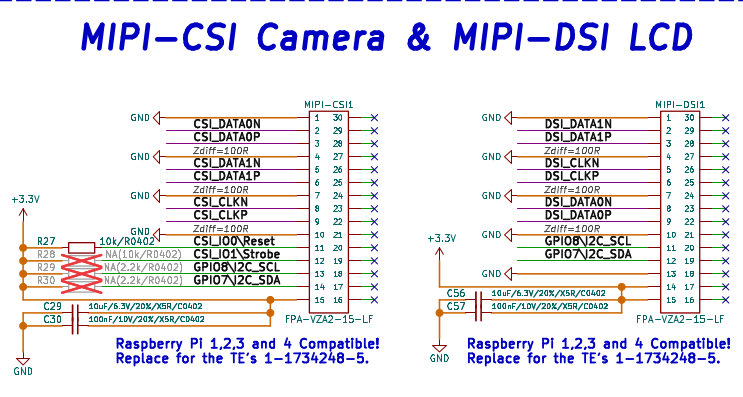
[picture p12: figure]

## Audio connector:

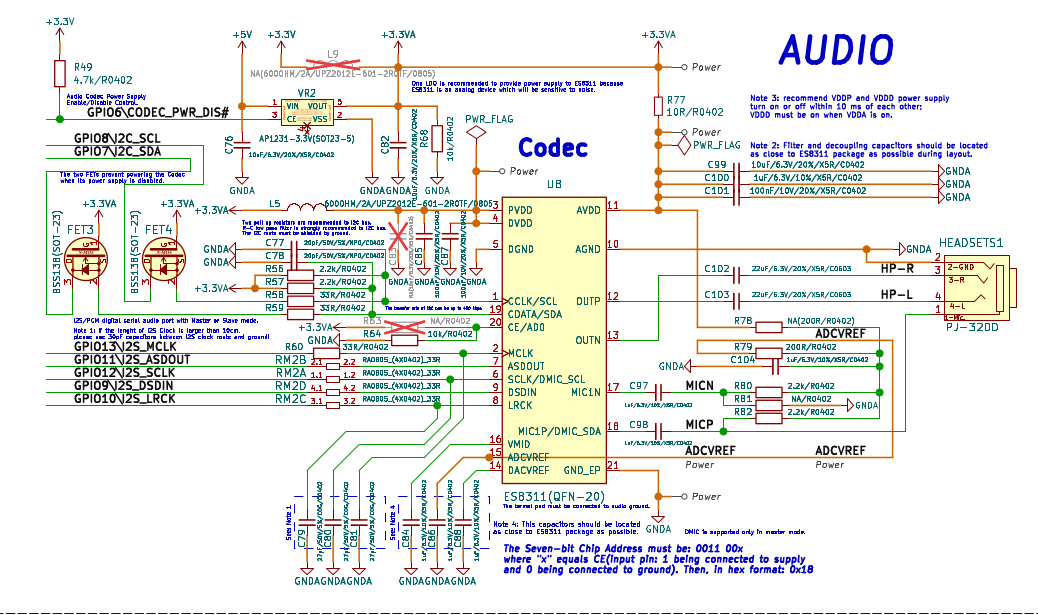
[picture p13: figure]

## USB-C connector:

It’s used for power supply, serial port programming and JTAG/debugging:

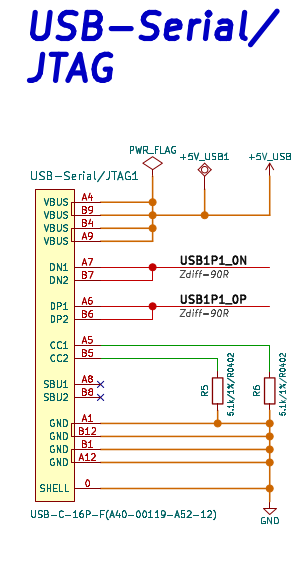
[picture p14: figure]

## Power supply path

ESP32-P4-PC can be powered by USB-C connector or Ethernet POE, the USB-C connector have priority i.e. if both are present the power will be taken from USB-C connector.

The voltage is labeled +5V-EXT and is used to charge LiPo battery.

There is option to detect this voltage with GPIO32 via voltage divider, this is not connected by default to keep GPIO32 free for other apps if the external power sense is not necessary.

The LiPo battery is used only if not External 5V power supply. In this case step up with U14 power all 5V peripherals. So everything is working even with no external power supply is present.

GPIO20 can be used to measure the battery charge. By default this port is not connected so GPIO20 is free for other applications if no battery sense is necessary.

## ESP32-P4-PC schematics:

ESP32-P4-PC (https://www.olimex.com/Products/IoT/ESP32-P4/ESP32-P4-PC/open-source-hardware) latest schematic is on GitHub (https://github.com/OLIMEX/ESP32-P4-PC/blob/main/HARDWARE/ESP32-P4-PC-Rev.B/ESP32-P4-PC_Rev_B.pdf)

# SOFTWARE:

ESP32-P4-PC (https://www.olimex.com/Products/IoT/ESP32-P4/ESP32-P4-PC/open-source-hardware) can be programmed with Espressif IDF. On Product web page there is demo code.

(https://github.com/vsladkov/reload-emulator)

# Revision History

Revision 1.0 February 2026

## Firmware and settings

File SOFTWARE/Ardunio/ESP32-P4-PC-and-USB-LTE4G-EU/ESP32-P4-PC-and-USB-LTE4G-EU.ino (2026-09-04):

#include <Arduino.h>

/*
  ESP32-P4-PC <-> USB-LTE4G-EU UART demo

  Goal:
    This sketch tests UART communication between an OLIMEX ESP32-P4-PC
    and an OLIMEX USB-LTE4G-EU / USB-LTE4G-EU-ANT modem board.

  Purpose:
    The ESP32-P4-PC sends basic AT commands to the LTE modem and prints
    the modem responses to the Arduino Serial Monitor. After startup, the
    sketch waits for manual AT command input from the Serial Monitor.

  Important hardware notes:
    The USB-LTE4G-EU modem UART works at 1.8 V logic level.
    The ESP32-P4-PC UEXT UART works at 3.3 V logic level.

    A level shifter is required between the two boards.
    OLIMEX UEXT-LVL-SHIFT can be used for this purpose.

  Connection:
    ESP32-P4-PC <-> UEXT-LVL-SHIFT:
      Connect these two boards with a UEXT cable.

    USB-LTE4G-EU:
      Power the USB-LTE4G-EU board from its own USB cable.

    USB-LTE4G-EU EXT1 header <-> UEXT-LVL-SHIFT UEXT_1.65V_to_5V5:
      Use 4 male-female jumper wires from the USB-LTE4G-EU EXT1 header
      to the low-voltage side of the UEXT-LVL-SHIFT board:

      USB-LTE4G-EU EXT1 pin 8 / VDD_EXT -> pin 1 of UEXT_1.65V_to_5V5
      USB-LTE4G-EU EXT1 pin 2 / GND     -> pin 2 of UEXT_1.65V_to_5V5
      USB-LTE4G-EU EXT1 pin 3 / TX      -> pin 4 of UEXT_1.65V_to_5V5
      USB-LTE4G-EU EXT1 pin 4 / RX      -> pin 3 of UEXT_1.65V_to_5V5

  Modem sleep note:
    The LTE module can enter sleep mode. This demo sends:

      AT+QSCLK=0

    during startup to disable modem sleep mode.
*/

static const int LTE_RX_PIN = 38;        // P4 RX <- LTE TXD via level shifter
static const int LTE_TX_PIN = 37;        // P4 TX -> LTE RXD via level shifter
static const uint32_t LTE_BAUD = 115200;

HardwareSerial LTE(1);

char inputLine[160];
size_t inputLen = 0;
uint32_t lastWaitingPrint = 0;

void sendCommand(const char *cmd, uint32_t waitMs = 1500) {
  Serial.println();
  Serial.print(">> ");
  Serial.println(cmd);

  while (LTE.available()) {
    LTE.read();
  }

  LTE.print(cmd);
  LTE.print("\r\n");

  bool gotResponse = false;
  uint32_t start = millis();

  while (millis() - start < waitMs) {
    while (LTE.available()) {
      Serial.write(LTE.read());
      gotResponse = true;
    }
    delay(1);
  }

  if (!gotResponse) {
    Serial.println("(no bytes received from LTE UART)");
  }
}

void setup() {
  Serial.begin(115200);
  delay(2000);

  Serial.println();
  Serial.println("=== ESP32-P4-PC LTE UART DEMO ===");
  Serial.println("Console: Serial over USB CDC, 115200 baud");
  Serial.println("Modem:   UART1, 115200 baud");
  Serial.println();

  Serial.println("Purpose:");
  Serial.println("  Test AT command communication with USB-LTE4G-EU over UART.");
  Serial.println("  A level shifter is required: modem UART is 1.8 V, P4 UEXT is 3.3 V.");
  Serial.println("  The USB-LTE4G-EU board must be powered from USB.");
  Serial.println();

  Serial.printf("Chip: %s rev %u\n", ESP.getChipModel(), ESP.getChipRevision());
  Serial.printf("Flash: %lu MB\n", (unsigned long)(ESP.getFlashChipSize() / 1024 / 1024));
  Serial.printf("PSRAM: %lu MB\n", (unsigned long)(ESP.getPsramSize() / 1024 / 1024));
  Serial.println();

  LTE.begin(LTE_BAUD, SERIAL_8N1, LTE_RX_PIN, LTE_TX_PIN);
  delay(2000);

  Serial.println("Startup modem probe:");
  sendCommand("AT");
  sendCommand("AT");
  sendCommand("AT");
  sendCommand("AT+QSCLK=0");   // Disable modem sleep mode.
  sendCommand("ATI");
  sendCommand("AT+CPIN?");
  sendCommand("AT+CSQ");

  Serial.println();
  Serial.println("Ready. Type AT commands and press Enter.");
  Serial.println("Examples: AT, ATI, AT+CPIN?, AT+CSQ, AT+CEREG?, AT+COPS?");
  Serial.println();

  lastWaitingPrint = millis();
}

void loop() {
  while (LTE.available()) {
    Serial.write(LTE.read());
  }

  while (Serial.available()) {
    char c = Serial.read();

    if (c == '\r') {
      continue;
    }

    if (c == '\n') {
      if (inputLen > 0) {
        inputLine[inputLen] = '\0';
        sendCommand(inputLine);
        inputLen = 0;
        lastWaitingPrint = millis();
      }
      continue;
    }

    if (inputLen < sizeof(inputLine) - 1) {
      inputLine[inputLen++] = c;
    } else {
      inputLen = 0;
      Serial.println("Input too long, cleared.");
    }
  }

  if (millis() - lastWaitingPrint >= 30000) {
    Serial.println("Waiting for AT command input...");
    Serial.println("Try: AT, ATI, AT+CPIN?, AT+CSQ, AT+CEREG?, AT+COPS?");
    lastWaitingPrint = millis();
  }
}

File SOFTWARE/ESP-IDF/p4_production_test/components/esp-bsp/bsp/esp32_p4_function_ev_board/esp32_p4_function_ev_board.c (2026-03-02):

/*
 * SPDX-FileCopyrightText: 2024-2025 Espressif Systems (Shanghai) CO LTD
 *
 * SPDX-License-Identifier: Apache-2.0
 */

#include <string.h>
#include "sdkconfig.h"
#include "driver/gpio.h"
#include "driver/ledc.h"
#include "esp_err.h"
#include "esp_log.h"
#include "esp_check.h"
#include "esp_spiffs.h"
#include "esp_lcd_panel_ops.h"
#include "esp_lcd_mipi_dsi.h"
#include "esp_ldo_regulator.h"
#include "esp_vfs_fat.h"
#include "usb/usb_host.h"
#include "sd_pwr_ctrl_by_on_chip_ldo.h"


#if CONFIG_BSP_LCD_TYPE_1024_600
#include "esp_lcd_ek79007.h"
#elif CONFIG_BSP_LCD_TYPE_HDMI
#include "esp_lcd_lt8912b.h"
#else
#include "esp_lcd_ili9881c.h"
#endif

#include "bsp/esp32_p4_function_ev_board.h"
#include "bsp/display.h"
#include "bsp/touch.h"
#include "esp_lcd_touch_gt911.h"
#include "bsp_err_check.h"
#include "esp_codec_dev_defaults.h"
#include "esp_video_device.h"
#include "esp_video_init.h"

static const char *TAG = "ESP32_P4_EV";

#if (BSP_CONFIG_NO_GRAPHIC_LIB == 0)
static lv_indev_t *disp_indev = NULL;
#endif // (BSP_CONFIG_NO_GRAPHIC_LIB == 0)

static sdmmc_card_t *bsp_sdcard = NULL;    // uSD card handle
static bool i2c_initialized = false;
static bool spi_sd_initialized = false;
static sd_pwr_ctrl_handle_t pwr_ctrl_handle = NULL; //SD LDO handle
static TaskHandle_t usb_host_task;  // USB Host Library task
#if (ESP_IDF_VERSION >= ESP_IDF_VERSION_VAL(5, 3, 0))
static i2c_master_bus_handle_t i2c_handle = NULL;  // I2C Handle
#endif
static i2s_chan_handle_t i2s_tx_chan = NULL;
static i2s_chan_handle_t i2s_rx_chan = NULL;
static const audio_codec_data_if_t *i2s_data_if = NULL;  /* Codec data interface */
static bsp_lcd_handles_t disp_handles;
static esp_ldo_channel_handle_t disp_phy_pwr_chan = NULL;
static esp_lcd_touch_handle_t tp = NULL;
static esp_lcd_panel_io_handle_t tp_io_handle = NULL;

/* Can be used for `i2s_std_gpio_config_t` and/or `i2s_std_config_t` initialization */
#define BSP_I2S_GPIO_CFG       \
    {                          \
        .mclk = BSP_I2S_MCLK,  \
        .bclk = BSP_I2S_SCLK,  \
        .ws = BSP_I2S_LCLK,    \
        .dout = BSP_I2S_DOUT,  \
        .din = BSP_I2S_DSIN,   \
        .invert_flags = {      \
            .mclk_inv = false, \
            .bclk_inv = false, \
            .ws_inv = false,   \
        },                     \
    }

/* This configuration is used by default in `bsp_extra_audio_init()` */
#define BSP_I2S_DUPLEX_MONO_CFG(_sample_rate)                                                         \
    {                                                                                                 \
        .clk_cfg = I2S_STD_CLK_DEFAULT_CONFIG(_sample_rate),                                          \
        .slot_cfg = I2S_STD_PHILIP_SLOT_DEFAULT_CONFIG(I2S_DATA_BIT_WIDTH_16BIT, I2S_SLOT_MODE_MONO), \
        .gpio_cfg = BSP_I2S_GPIO_CFG,                                                                 \
    }

esp_err_t bsp_i2c_init(void)
{
    /* I2C was initialized before */
    if (i2c_initialized) {
        return ESP_OK;
    }

    i2c_master_bus_config_t i2c_bus_conf = {
        .clk_source = I2C_CLK_SRC_DEFAULT,
        .sda_io_num = BSP_I2C_SDA,
        .scl_io_num = BSP_I2C_SCL,
        .i2c_port = BSP_I2C_NUM,
    };
    BSP_ERROR_CHECK_RETURN_ERR(i2c_new_master_bus(&i2c_bus_conf, &i2c_handle));

    i2c_initialized = true;

    return ESP_OK;
}

esp_err_t bsp_i2c_deinit(void)
{
    if (i2c_initialized && i2c_handle) {
        BSP_ERROR_CHECK_RETURN_ERR(i2c_del_master_bus(i2c_handle));
        i2c_initialized = false;
    }
    return ESP_OK;
}

i2c_master_bus_handle_t bsp_i2c_get_handle(void)
{
    return i2c_handle;
}

sdmmc_card_t *bsp_sdcard_get_handle(void)
{
    return bsp_sdcard;
}

void bsp_sdcard_get_sdmmc_host(const int slot, sdmmc_host_t *config)
{
    assert(config);

    sdmmc_host_t host_config = SDMMC_HOST_DEFAULT();
    host_config.slot = slot;
    host_config.max_freq_khz = SDMMC_FREQ_HIGHSPEED;

    memcpy(config, &host_config, sizeof(sdmmc_host_t));
}

void bsp_sdcard_get_sdspi_host(const int slot, sdmmc_host_t *config)
{
    assert(config);

    sdmmc_host_t host_config = SDSPI_HOST_DEFAULT();
    host_config.slot = slot;

    memcpy(config, &host_config, sizeof(sdmmc_host_t));
}

void bsp_sdcard_sdmmc_get_slot(const int slot, sdmmc_slot_config_t *config)
{
    assert(config);
    memset(config, 0, sizeof(sdmmc_slot_config_t));

    /* SD card is connected to Slot 0 pins. Slot 0 uses IO MUX, so not specifying the pins here */
    config->cd = SDMMC_SLOT_NO_CD;
    config->wp = SDMMC_SLOT_NO_WP;
    config->width = 4;
    config->flags = 0;
}
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

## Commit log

2026-02-17 initial upload
    [ESP32-P4-PC_Rev_B-B_Cu.gbr, ESP32-P4-PC_Rev_B-B_Mask.gbr, ESP32-P4-PC_Rev_B-B_Paste.gbr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]
2026-03-02 ESP-IDF production test
    New demo
    [partitions.csv]
